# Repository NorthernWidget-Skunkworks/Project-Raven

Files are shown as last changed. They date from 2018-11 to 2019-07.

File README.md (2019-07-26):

# Project-Raven
Eagle designs for a high gain current amplifier board, for either bench-top or field use 

<br>
<br />This work is licensed under a <a rel="license" href="http://creativecommons.org/licenses/by-sa/4.0/">Creative Commons Attribution-ShareAlike 4.0 International License</a>.

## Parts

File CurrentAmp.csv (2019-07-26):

Qty | Value | Device | Package | Parts | Description | DIGIKEY | DISP | MF | MPN | VALUE_PART
1 |  | CONN_022.54MM_SCREWTERM | 1X02_2.54_SCREWTERM | J1 | Multi connection point. Often used as Generic Header-pin footprint for 0.1 inch spaced/style header connections
1 | 0.1uF | C-EUC0603 | C0603 | C4 | CAPACITOR, European symbol
1 | 1.5uF | C-EUC0603 | C0603 | C1 | CAPACITOR, European symbol
1 | 1.62M | R-EU_R0603 | R0603 | R4 | RESISTOR, European symbol |  |  | Yageo
2 | 100k | R-EU_R0603 | R0603 | R8, R9 | RESISTOR, European symbol |  |  | Yageo
2 | 10R | R-EU_R0603 | R0603 | R2, R3 | RESISTOR, European symbol |  |  | Yageo
1 | 180k | R-EU_R0603 | R0603 | R5 | RESISTOR, European symbol |  |  | Yageo
2 | 22uF | C-EUC0805 | C0805 | C2, C3 | CAPACITOR, European symbol
2 | 330 | R-EU_R0603 | R0603 | R6, R7 | RESISTOR, European symbol |  |  | Yageo
1 | 50m | R-EU_R0805 | R0805 | R1 | RESISTOR, European symbol
1 | CONN_42.54_SCREW | CONN_42.54_SCREW | 1X04_SCREW | J2 | Genaric 4 pin connector | ED10563-ND |  | On Shore | OSTVN04A150
1 | INA212DCK | INA212DCK | DCK_R-PDSO-G6 | U1 | INA21x - Analog Output Current Sense Amplifier | 296-40128-1-ND | INA212 | TI | INA212BIDCKR
1 | JUMPER-SMT_3_1-NC_PASTE_SILK | JUMPER-SMT_3_1-NC_PASTE_SILK | SMT-JUMPER_3_1-NC_PASTE_SILK | JP1 | Normally closed solder jumper (1 of 2 connections)
1 | MCP6041 | MCP6041 | SOT23-5 | U2 | MCP6041 - Low Power Rail to Rail Op-Amp | MCP6041T-I/OTCT-ND | MCP6041 | Microchip | MCP6041T-I/OT

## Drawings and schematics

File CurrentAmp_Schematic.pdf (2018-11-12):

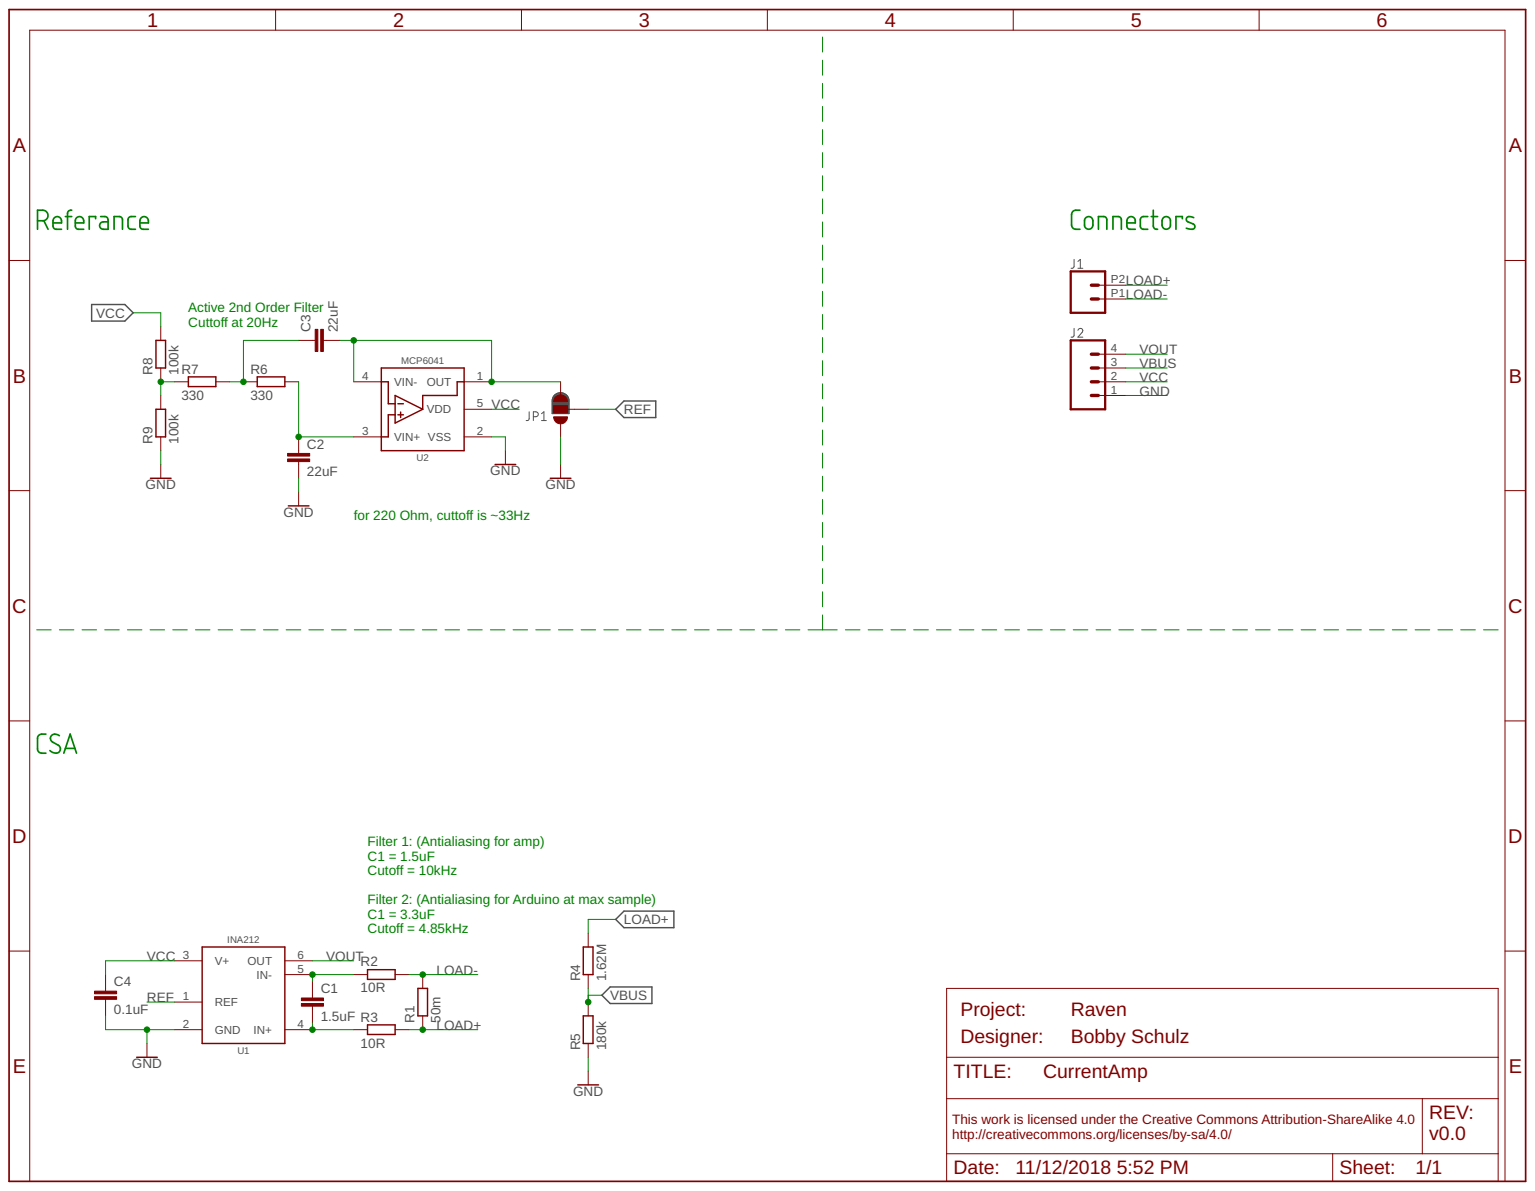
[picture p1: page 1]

Active 2nd Order Filter Cuttoff at 20Hz

for 220 Ohm, cuttoff is ~33Hz

Filter 1: (Antialiasing for amp)
Cutoff = 10kHz Filter 2: (Antialiasing for Arduino at max sample)

This work is licensed under the Creative Commons Attribution-ShareAlike 4.0 http://creativecommons.org/licenses/by-sa/4.0/ | REV: v0.0

Date: 11/12/2018 5:52 PM | Sheet: 1/1

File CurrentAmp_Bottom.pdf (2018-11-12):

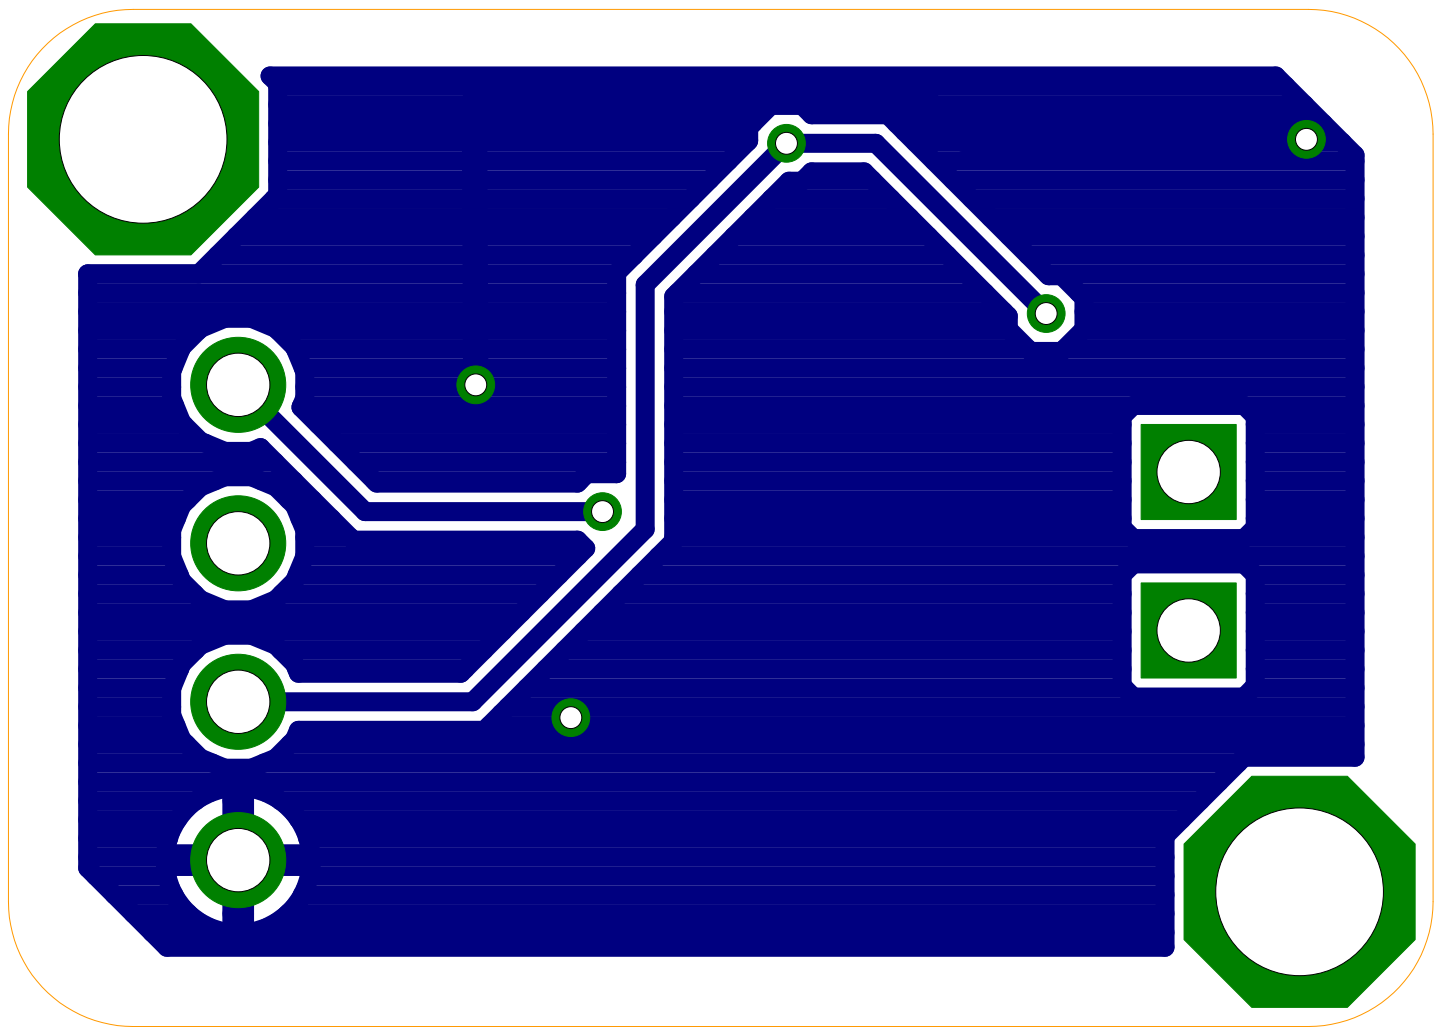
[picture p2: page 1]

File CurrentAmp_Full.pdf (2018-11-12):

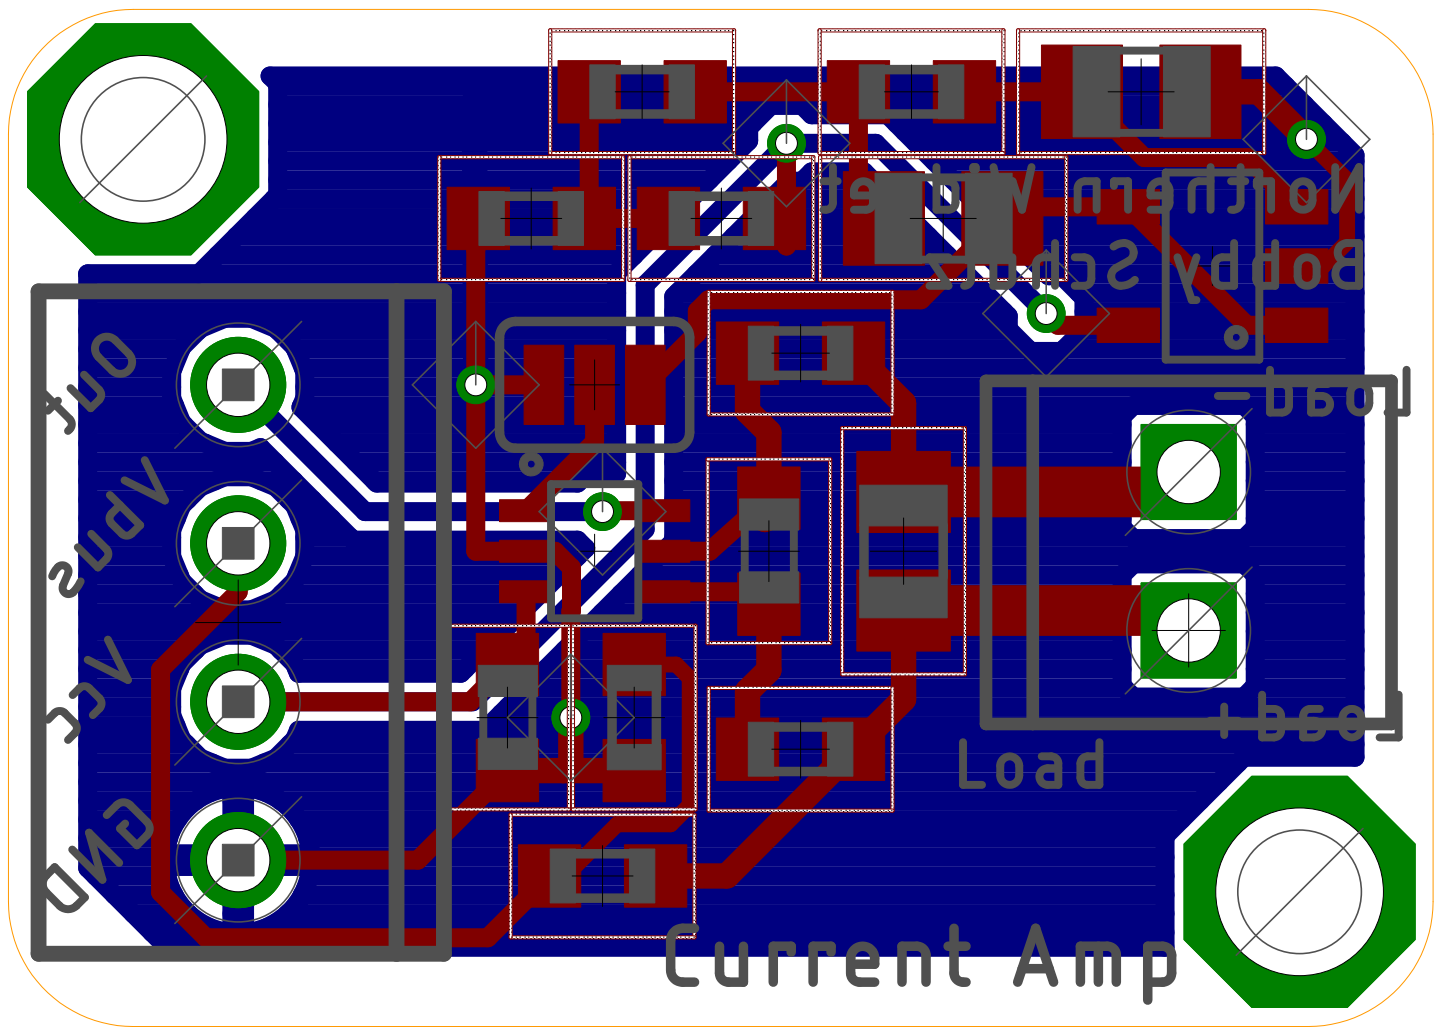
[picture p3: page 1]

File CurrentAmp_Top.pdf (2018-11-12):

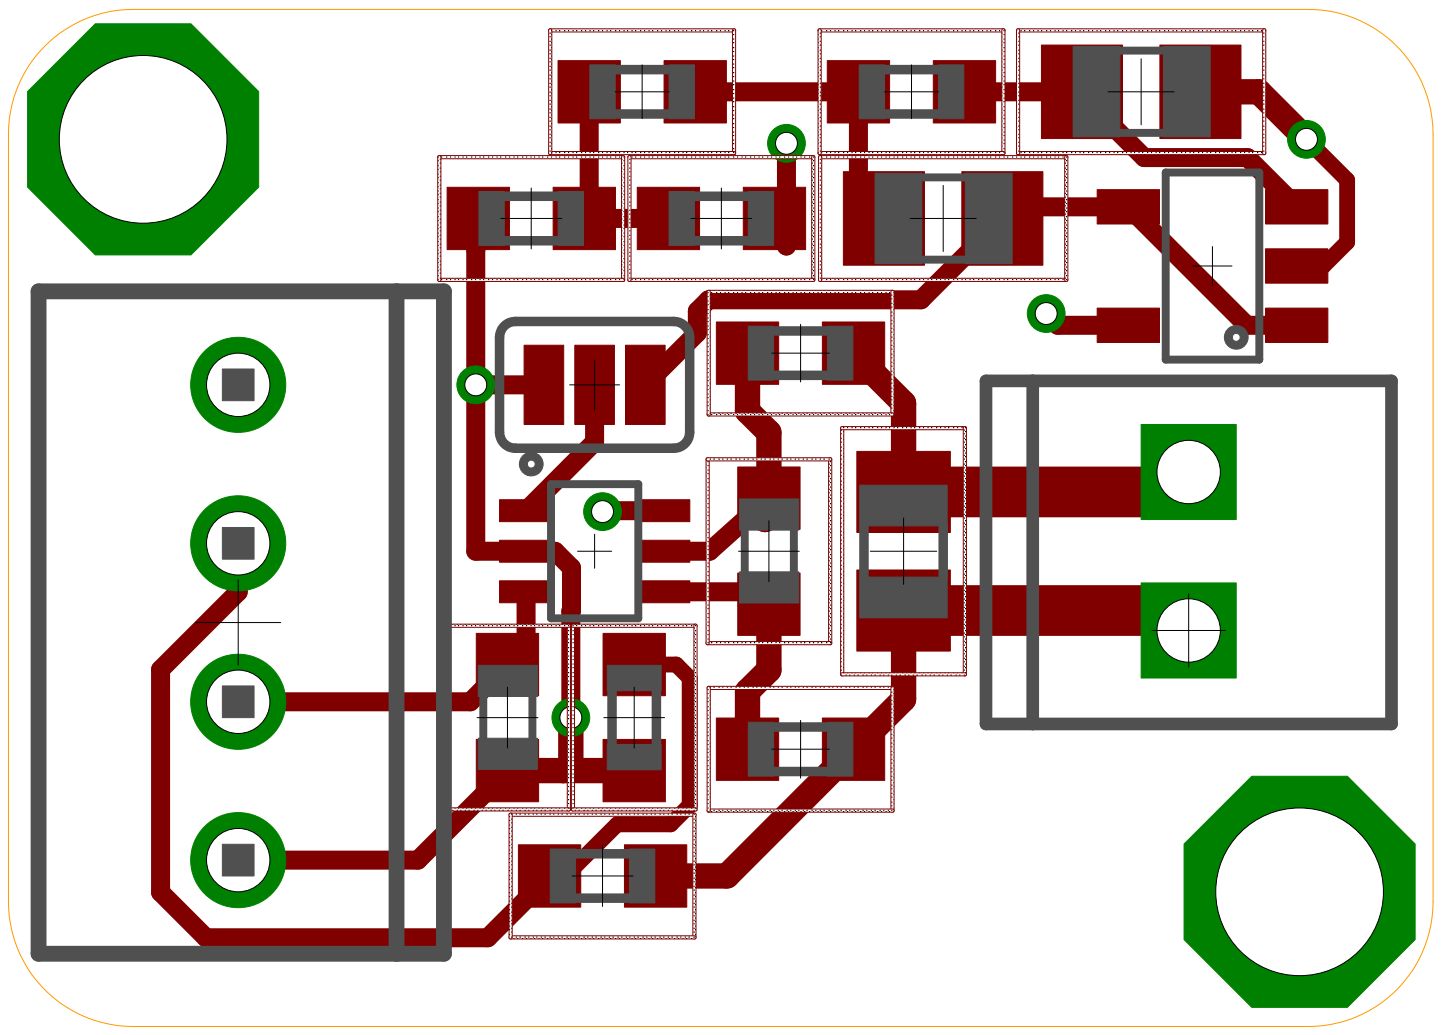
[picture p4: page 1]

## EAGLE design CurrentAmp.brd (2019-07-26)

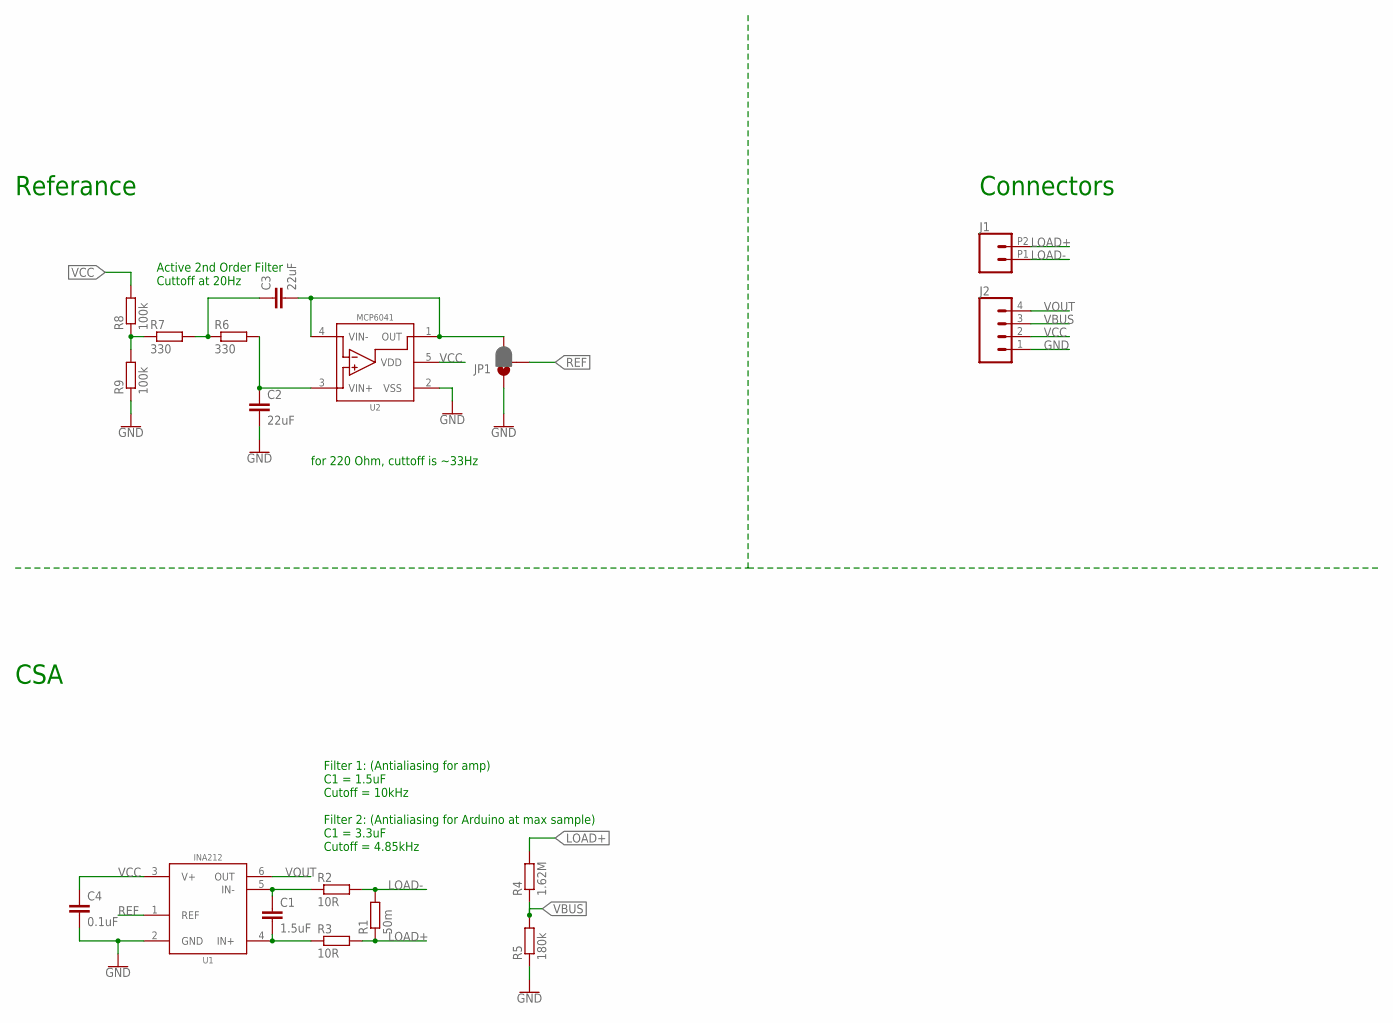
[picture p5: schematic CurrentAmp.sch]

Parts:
C1: 1.5uF; C0603
C2, C3: 22uF; C0805
C4: 0.1uF; C0603
J1: CONN_022.54MM_SCREWTERM; 1X02_2.54_SCREWTERM
J2: CONN_42.54_SCREW; 1X04_SCREW
JP1: JUMPER-SMT_3_1-NC_PASTE_SILK; SMT-JUMPER_3_1-NC_PASTE_SILK
R1: 50m; R0805
R2, R3: 10R; R0603
R4: 1.62M; R0603
R5: 180k; R0603
R6, R7: 330; R0603
R8, R9: 100k; R0603
U1: INA212DCK; DCK_R-PDSO-G6
U2: MCP6041; SOT23-5

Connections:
GND: C2.2, C4.2, J2.1, JP1.1, R5.1, R9.1, U1.2 (GND), U2.2 (VSS)
LOAD+: J1.P2 (2), R1.1, R3.2, R4.2
LOAD-: J1.P1 (1), R1.2, R2.2
unnamed: C1.1, R2.1, U1.5 (IN-)
unnamed: C1.2, R3.1, U1.4 (IN+)
unnamed: C3.2, JP1.3, U2.1 (OUT), U2.4 (VIN-)
unnamed: C2.1, R6.2, U2.3 (VIN+)
unnamed: C3.1, R6.1, R7.2
unnamed: R7.1, R8.1, R9.2
REF: JP1.2, U1.1 (REF)
VBUS: J2.3, R4.1, R5.2
VCC: C4.1, J2.2, R8.2, U1.3 (V+), U2.5 (VDD)
VOUT: J2.4, U1.6 (OUT)

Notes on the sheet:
Filter 1: (Antialiasing for amp) C1 = 1.5uF Cutoff = 10kHz Filter 2: (Antialiasing for Arduino at max sample) C1 = 3.3uF Cutoff = 4.85kHz
Active 2nd Order Filter Cuttoff at 20Hz
CSA
Referance
Connectors
for 220 Ohm, cuttoff is ~33Hz

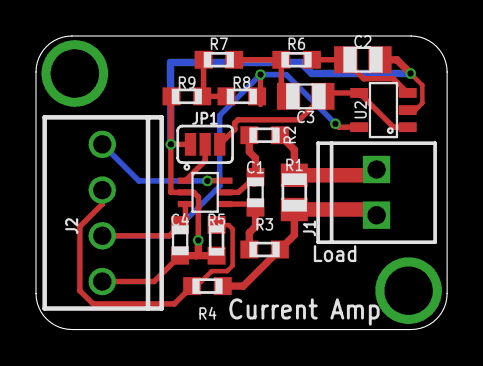
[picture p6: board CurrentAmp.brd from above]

Board: 2 copper layers, 22.8 x 16.3 mm, 18 parts (0 on the bottom side), 13 nets.

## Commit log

2018-02-28 Initial commit
    Initial commit containing board file, schematic, as well as the gerber files used for the first order of these boards
    [CurrentAmp.brd, CurrentAmp.sch]
2018-11-12 Minor schematic cleanup
    [CurrentAmp.brd, CurrentAmp.sch]
2018-11-12 Schematic cleanup, added PDFs
    [CurrentAmp.sch]
2019-07-26 Added BoM and cleaned up part ID info on board
    [CurrentAmp.brd, CurrentAmp.csv]

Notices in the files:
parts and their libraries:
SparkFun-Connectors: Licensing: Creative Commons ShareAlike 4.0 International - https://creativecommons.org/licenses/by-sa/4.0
